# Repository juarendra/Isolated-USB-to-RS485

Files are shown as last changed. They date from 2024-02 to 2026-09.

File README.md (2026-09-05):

# Industrial USB to RS485 Adapter

USB Type-C to isolated half-duplex RS485 interface for Modbus RTU and other UART-based industrial networks.

<p align="center">
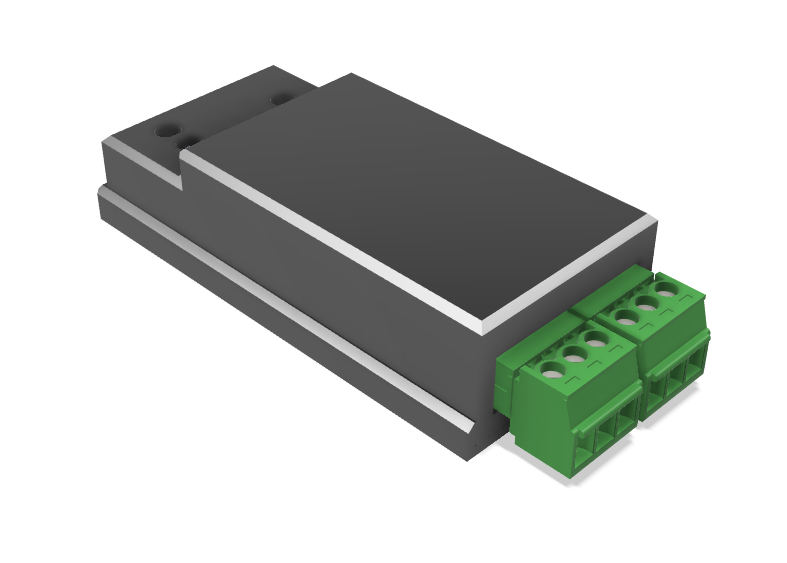
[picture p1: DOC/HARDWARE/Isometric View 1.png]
Industrial USB to RS485 adapter isometric view
  
</p>

## Product Summary

This board converts a USB serial connection into an electrically isolated RS485 bus. It is suitable for connecting a computer, single-board computer, or industrial controller to RS485/Modbus RTU equipment.

```text
USB Type-C -> FT231XS UART -> ADuM1201 isolation -> MAX485 -> RS485 A/B
```

The design files are provided for evaluation, manufacturing, and integration. Read the limitations and validation notes before using the board in a safety-critical or compliance-regulated product.

## Features

- USB Type-C USB 2.0 connection
- FTDI FT231XS USB-to-UART bridge
- 3.3 V UART I/O configuration
- Isolated UART data path using ADuM1201ARZ
- Isolated 5 V supply using IL0505S
- MAX485 half-duplex RS485 transceiver
- RS485 A, B, and isolated ground connector
- Selectable RS485 termination and bias networks
- RS485 transient protection using SM712, TBU, and TISP devices
- TX, RX, and power status indicators
- Resettable USB input protection
- Separate isolated 5 V output connector
- Eagle schematic, board, libraries, Gerber archive, 3D model, and enclosure files

<p align="center">
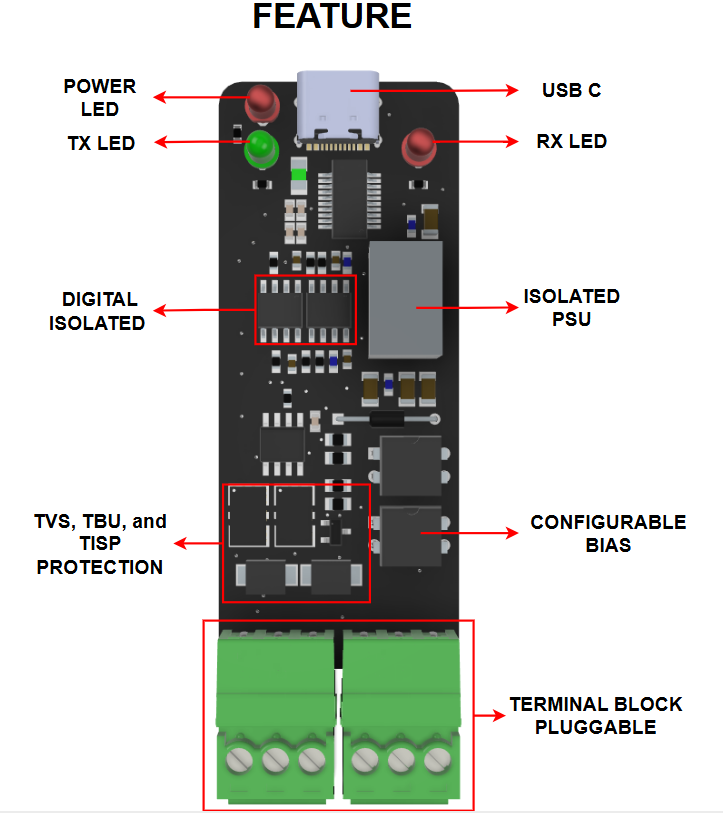
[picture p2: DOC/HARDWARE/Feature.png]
Industrial USB to RS485 adapter feature overview
  
</p>

## Quick Start

1. Connect the board to a host computer using a USB Type-C data cable.
2. Install the FTDI VCP driver if the operating system does not install it automatically.
3. Identify the new serial port.
4. Connect RS485 `A`, `B`, and optionally `GNDA` to the target equipment.
5. Configure the host application for the target baud rate, parity, stop bits, and protocol.
6. Enable termination only when this adapter is at a physical end of the RS485 bus.
7. Enable bias only when this adapter is the designated bias point for the bus.

## Connector Pinout

See the visual pinout: [`DOC/HARDWARE/Pinout.png`](DOC/HARDWARE/Pinout.png).

| Connector | Pin | Function |
|---|---:|---|
| RS485 | 1 | `GNDA` / isolated ground |
| RS485 | 2 | `B` |
| RS485 | 3 | `A` |
| POWER | 1 | `GNDA` |
| POWER | 2 | `VCC`, isolated 5 V |
| POWER | 3 | `VCC`, isolated 5 V |

Confirm connector orientation against the silkscreen and pinout image before wiring.

## Design Files

| Resource | Location |
|---|---|
| Schematic PDF | [`PDF/Schematic.pdf`](PDF/Schematic.pdf) |
| Eagle schematic | [`PCB-EAGLE/IndustrialUSBtoModbus.sch`](PCB-EAGLE/IndustrialUSBtoModbus.sch) |
| Eagle board | [`PCB-EAGLE/IndustrialUSBtoModbus.brd`](PCB-EAGLE/IndustrialUSBtoModbus.brd) |
| Manufacturing Gerbers | [`CAD-CAM/Gerber.zip`](CAD-CAM/Gerber.zip) |
| Production PCB | [`PCB-EAGLE/IndustrialUSBtoModbus_Production.brd`](PCB-EAGLE/IndustrialUSBtoModbus_Production.brd) |
| Production Gerbers | [`CAD-CAM/Gerber_Production.zip`](CAD-CAM/Gerber_Production.zip) |
| Production CAM job | [`CAD-CAM/IndustrialUSBtoModbus v2.cam`](CAD-CAM/IndustrialUSBtoModbus%20v2.cam) |
| Board dimensions | [`DOC/Dimension.pdf`](DOC/Dimension.pdf) |
| STEP model | [`3D/IndustrialUSBtoModbus.step`](3D/IndustrialUSBtoModbus.step) |
| Enclosure models | [`3D/Case/`](3D/Case/) |
| Custom Eagle libraries | [`PCB-EAGLE/lib/`](PCB-EAGLE/lib/) |

Detailed documentation is in [`docs/`](docs/).

For manufacturing, use the files marked **Production**. The production Gerber archive contains Gerber, drill, solder-paste, pick-and-place, job, and ODB++ outputs generated from the production PCB revision.

## Important Limitations

- This is a half-duplex RS485 hardware interface; it does not implement Modbus protocol in hardware.
- RS485 termination, bias values, isolation spacing, and protection ratings require system-level verification.
- Cable length, baud rate, node count, and bus topology depend on the transceiver, cable, and installation.
- Custom FTDI VID/PID programming requires valid ownership/licensing and separate production configuration.

## Buyer Information

Before purchasing or manufacturing, review:

- [`docs/BUYER-GUIDE.md`](docs/BUYER-GUIDE.md) for compatibility and ordering checks
- [`docs/HARDWARE.md`](docs/HARDWARE.md) for circuit behavior and configuration
- [`docs/VALIDATION.md`](docs/VALIDATION.md) for required production tests
- [`docs/FTDI-PROGRAMMING.md`](docs/FTDI-PROGRAMMING.md) for FT231XS production programming
- [`docs/FILES.md`](docs/FILES.md) for the complete repository map

## License

No license is currently declared. Contact the repository owner for permission to manufacture, modify, or redistribute this design.

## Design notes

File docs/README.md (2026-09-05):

# Documentation

Use these pages when evaluating, buying, assembling, or integrating the adapter.

| Guide | Use it for |
|---|---|
| [`BUYER-GUIDE.md`](BUYER-GUIDE.md) | Compatibility, ordering, wiring, and acceptance checks |
| [`HARDWARE.md`](HARDWARE.md) | Signal path, power domains, protection, and switches |
| [`VALIDATION.md`](VALIDATION.md) | Electrical, functional, protection, and environmental tests |
| [`FTDI-PROGRAMMING.md`](FTDI-PROGRAMMING.md) | FT231XS EEPROM and CBUS production profile |
| [`FILES.md`](FILES.md) | Design-file locations and naming rules |

## Recommended Reading Order

1. Read the root [`README.md`](../README.md) for product scope and limitations.
2. Read [`BUYER-GUIDE.md`](BUYER-GUIDE.md) before ordering or wiring.
3. Read [`HARDWARE.md`](HARDWARE.md) before changing the PCB or configuration.
4. Use [`VALIDATION.md`](VALIDATION.md) to define production acceptance tests.

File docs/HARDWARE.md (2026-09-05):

# Hardware Reference

## Signal Path

```text
USB Type-C
  |
  +-- FT231XS-R USB-to-UART
          |
          +-- TXD / RXD / TXEN
                  |
                  +-- ADuM1201ARZ digital isolation
                          |
                          +-- MAX485CSA+ half-duplex transceiver
                                  |
                                  +-- protected A/B connector
```

## Power Domains

| Domain | Nets | Purpose |
|---|---|---|
| USB side | `+5V`, `GND`, `+3V3` | USB connector and FT231XS |
| Isolated bus side | `VCC`, `GNDA` | MAX485, RS485 connector, protection |

`IL0505S` transfers power across the isolation barrier. The two ADuM1201 devices transfer data and direction control without a galvanic signal connection.

## USB-C Configuration

The current revision includes USB-C sink pull-down resistors:

```text
CC1 -> R4 = 5.1 kOhm -> GND
CC2 -> R8 = 5.1 kOhm -> GND
```

These resistors identify the board as a USB device/sink to a USB-C host. `SBU1` and `SBU2` remain unused for this USB 2.0 design.

## RS485 Configuration

`S1` is associated with the single 120 ohm termination resistor `R6`. `S2` is associated with the 4.7 kOhm bias network. Confirm switch position and assembled resistance using a meter because termination must not be enabled at every node.

Recommended topology:

- One termination at each physical end of the main cable.
- Bias enabled at one intentional location, unless the system design specifies otherwise.
- Short stub connections.
- Twisted-pair cable with a suitable characteristic impedance.

### Bias Calculation

The schematic uses `R2 = 4.7 kOhm` from `VCC` to `A` and `R5 = 4.7 kOhm` from `B` to `GNDA`, enabled by `S2`.

For the single 120 ohm termination and an ideal 5 V isolated supply:

```text
I_bias = 5 V / (4.7 kOhm + 120 ohm + 4.7 kOhm)
       = approximately 0.525 mA

V(A) - V(B) = I_bias x 120 ohm
            = approximately 63 mV
```

This is lower than the commonly used 200 mV fail-safe design target. It is not automatically wrong because MAX485 and connected nodes contribute their own behavior, but the complete bus must be calculated and measured. Consider lower bias values only after checking total bus loading, driver current, termination count, and idle common-mode voltage.

With `S2` enabled, record:

- `V(A)` relative to `GNDA`.
- `V(B)` relative to `GNDA`.
- `V(A) - V(B)`.
- Bias current.

Enable bias at one intentional location only. Multiple bias networks can overload the bus and alter common-mode voltage.

### Protection and Fault Specification

The following are design targets and component-level references, not guaranteed board ratings. Fill in the final values after testing the assembled PCB and intended cable installation.

| Parameter | Current design reference | Final value/status |
|---|---|---|
| RS485 common-mode operating range | MAX485 and system specification | TBD by system test |
| Maximum A/B continuous voltage | MAX485 absolute maximum and protection coordination | TBD |
| Maximum line-to-`GNDA` voltage | TBU/TISP/TVS coordination | TBD |
| RS485 short-circuit duration | MAX485 thermal/fault test | TBD |
| TVS standoff voltage | SM712-02HTG datasheet | Verify against bus voltage |
| TBU trigger/current rating | TBU-CA065-200-WH datasheet | Verify per revision |
| TISP voltage/surge rating | TISP4240M3BJR-S datasheet | Verify per test waveform |
| SM712 clamp voltage | SM712-02HTG datasheet and test current | Verify at specified current |
| Surge return path | A/B -> protection -> `GNDA` -> installation return | Validate layout and wiring |

Do not convert these component references into an IEC, EMC, or surge claim without a defined test method and a passing test report.

### Protection Pin Review

Verify the exact manufacturer datasheet and package drawing against the Eagle library before assembly:

| Reference | Part | Required verification |
|---|---|---|
| `D4`, `D5` | `TBU-CA065-200-WH` | Current path pin 1 to pin 3, center pad/pin 2 treatment, package and orientation |
| `D1`, `D6` | `TISP4240M3BJR-S` | Pin polarity, line-to-ground connection, surge path, package |
| `D2` | `SM712-02HTG` | `TVS1`, `TVS2`, `COMMON` mapping, bidirectional behavior, package |

Use a pin-to-pin checklist, not symbol appearance alone:

1. Compare manufacturer pinout with Eagle symbol pin names.
2. Compare symbol pins with package pads in the board file.
3. Trace each line from connector to protection device to `MAX485`.
4. Confirm the TVS common pin returns to `GNDA`.
5. Confirm surge current does not cross the USB isolation barrier.
6. Recheck the physical footprint orientation using a populated-board drawing.

For the current Eagle library, the TBU symbol exposes only pins 1 and 3, while the package contains a center pad/pin 2. Do not infer an electrical function for pin 2 from the symbol. Confirm whether the selected manufacturer package defines it as no-connect, thermal pad, or another connection, then update the library and PCB if required.

## Protection Devices

- `SM712-02HTG`: RS485 line transient suppressor.
- `TBU-CA065-200-WH`: series fault-current limiting devices.
- `TISP4240M3BJR-S`: surge protection devices.
- `0ZCJ0010FF2E`: resettable USB input protection.

Protection performance depends on layout, grounding, surge return path, component tolerances, and installation wiring. Component presence is not equivalent to a compliance rating.

## Indicators

- `LED1`: local power indication.
- `LED3`: FTDI CBUS1 indication, intended for receive activity.
- `LED4`: FTDI CBUS2 indication, intended for transmit activity.

Exact LED behavior depends on FTDI CBUS configuration programmed into the device.

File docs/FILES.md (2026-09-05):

# Repository Map

## Main Folders

| Folder | Contents |
|---|---|
| `CAD-CAM/` | Manufacturing output archives |
| `DOC/` | Buyer-facing images and mechanical documents |
| `PDF/` | Printable schematic documentation |
| `PCB-EAGLE/` | Eagle source files and custom libraries |
| `3D/` | Board, enclosure, and mechanical models |
| `docs/` | Product, hardware, buyer, and validation documentation |

## Production Outputs

Use these files for the current manufacturing package:

| Output | Location |
|---|---|
| Production Eagle board | [`PCB-EAGLE/IndustrialUSBtoModbus_Production.brd`](../PCB-EAGLE/IndustrialUSBtoModbus_Production.brd) |
| Production Gerber/ODB++ archive | [`CAD-CAM/Gerber_Production.zip`](../CAD-CAM/Gerber_Production.zip) |
| Production CAM job | [`CAD-CAM/IndustrialUSBtoModbus v2.cam`](../CAD-CAM/IndustrialUSBtoModbus%20v2.cam) |

The production archive includes copper, solder mask, solder paste, silkscreen, board profile, drill, job, ODB++ data, and front-side pick-and-place output. Confirm the PCB revision and fabrication house rules before ordering.

## Naming Convention

New files should use:

- Uppercase folder names only for legacy design folders.
- Lowercase `docs/` for GitHub documentation.
- Lowercase, hyphen-separated names for new documentation files.
- Descriptive asset names, for example `rs485-adapter-pinout.png`.
- Stable revision suffixes when output changes, for example `gerbers-r02.zip`.

Existing Eagle source names are retained to avoid breaking library links and manufacturing references.

## Legacy Files

Files with names such as `IndustrialUSBtoModbus.b#1` are Eagle backup artifacts. They are retained for traceability but should not be used as the primary source. Use the `.sch` and `.brd` files listed above.

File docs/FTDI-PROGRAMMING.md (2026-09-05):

# FTDI Production Programming

The schematic assigns FTDI CBUS pins to RS485 direction control and activity indicators. These functions are configured in FTDI EEPROM; they are not guaranteed by PCB wiring alone.

## Required Profile

Program and record one approved profile for every production batch.

| EEPROM field | Required value |
|---|---|
| VID | Use an owned/licensed VID; do not copy another vendor's VID |
| PID | Approved product PID paired with the VID |
| Manufacturer string | Product owner approved text |
| Product description | `Industrial USB to RS485` or approved text |
| Serial number | Unique per device, or explicitly disabled by policy |
| VCP driver | Enabled if the product is used as a virtual COM port |
| CBUS0 | `TXDEN` / RS485 transmit-enable function, if supported by the exact FT231XS configuration tool |
| CBUS1 | `RXLED#` activity indication |
| CBUS2 | `TXLED#` activity indication |
| Inversion | Disabled unless validated by logic measurement |

## Important Direction-Control Clarification

The schematic net `TXEN_` connects FTDI `CBUS0` through `R33` to one ADuM1201 channel. The isolated output of that channel drives MAX485 `DE` and `/RE` together.

The exact CBUS0 function must produce the required timing and polarity for half-duplex RS485. Use the FTDI transmit-data-enable function, commonly shown as `TXDEN`, when available. Do not use `TXLED#` for direction control. Validate with an oscilloscope:

- `TXD` activity.
- `TXEN_` on the USB side.
- Isolated direction signal.
- MAX485 `DE`.
- MAX485 `/RE`.
- RS485 A/B driver activity.

If CBUS0 is used as a direction-control output, select the correct FTDI mode supported by the exact FT231XS revision and validate driver turn-around timing. Keep LED functions on CBUS1/CBUS2 only if the programmed modes match the schematic intent.

### Important FTDI Clarification

`TXDEN` is a hardware transmit-enable indication generated from USB-UART transmit activity. It is not the same signal as `TXD`, and it must remain asserted long enough for the complete outgoing UART character stream. Check the exact FTDI FT231X datasheet and FT_PROG option list for the installed device revision before freezing the EEPROM profile.

The schematic currently routes `CBUS0` through `R33` and an ADuM1201 channel to both MAX485 `DE` and `/RE`. That is an intentional half-duplex arrangement: transmit mode enables the driver and disables the receiver. Confirm that the inactive state is safe during USB attach, reset, suspend, and disconnect. A temporary incorrect state can cause bus contention.

### Recommended Production Record

Store the following with each hardware revision:

- FTDI part marking and silicon revision.
- FT_PROG version.
- EEPROM profile file or captured settings.
- VID/PID ownership record.
- Product and manufacturer strings.
- Serial-number allocation range.
- CBUS0/1/2 settings and polarity.
- Oscilloscope capture showing UART, `TXEN_`, `DE`, `/RE`, and A/B.

## Production Procedure

1. Connect the board to a controlled USB host or FTDI programming fixture.
2. Read and save the original EEPROM configuration.
3. Program the approved VID, PID, strings, serial policy, VCP setting, CBUS functions, and inversion settings.
4. Power-cycle the board.
5. Confirm USB enumeration and descriptor values.
6. Confirm COM-port creation.
7. Verify TX/RX indicators.
8. Verify RS485 direction timing and loopback communication.
9. Save the programmed profile and device serial number in the production record.

Never use an unlicensed VID/PID or ship devices with an untracked serial-number policy.

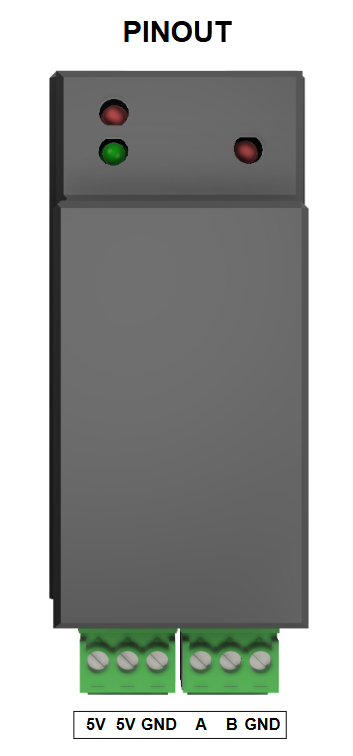
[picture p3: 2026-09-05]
DOC/HARDWARE/Pinout.png

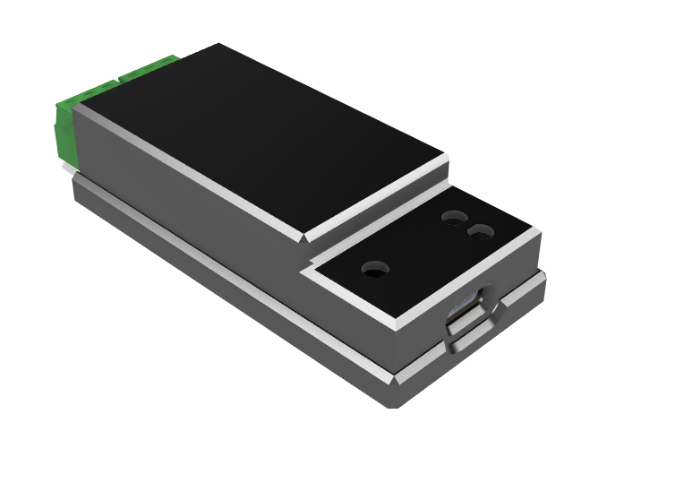
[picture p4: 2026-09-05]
DOC/HARDWARE/Isometric View 2.png

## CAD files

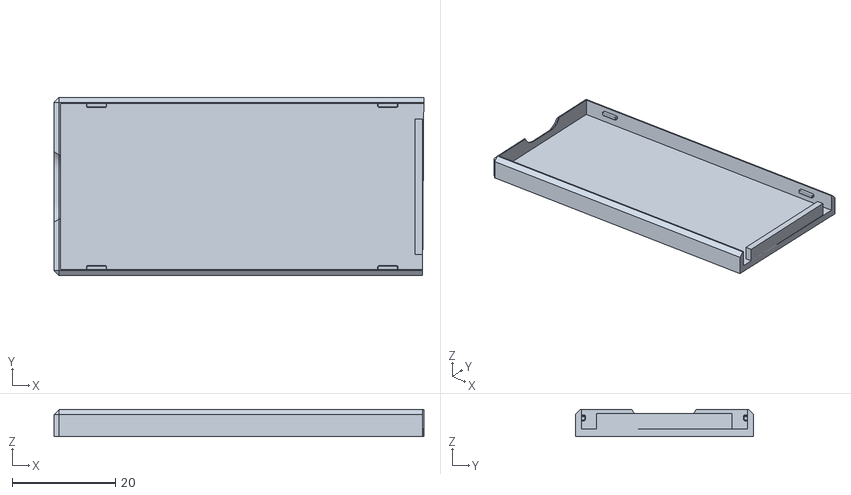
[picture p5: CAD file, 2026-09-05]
3D/Case/Bottom.stl
71.7 x 34.6 x 5.25

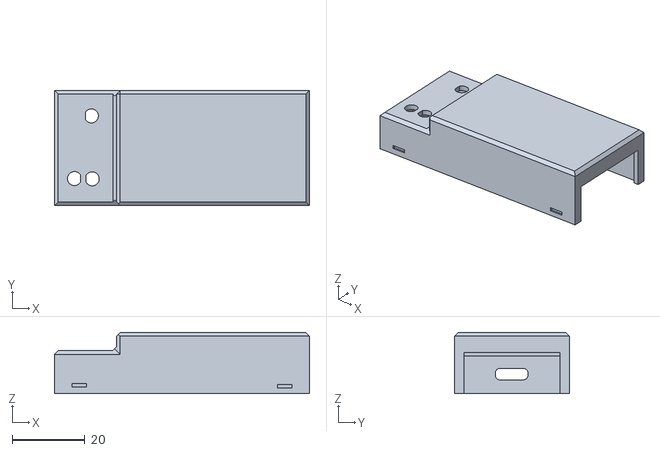
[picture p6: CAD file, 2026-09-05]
3D/Case/TOP.stl
70.0 x 31.6 x 16.8

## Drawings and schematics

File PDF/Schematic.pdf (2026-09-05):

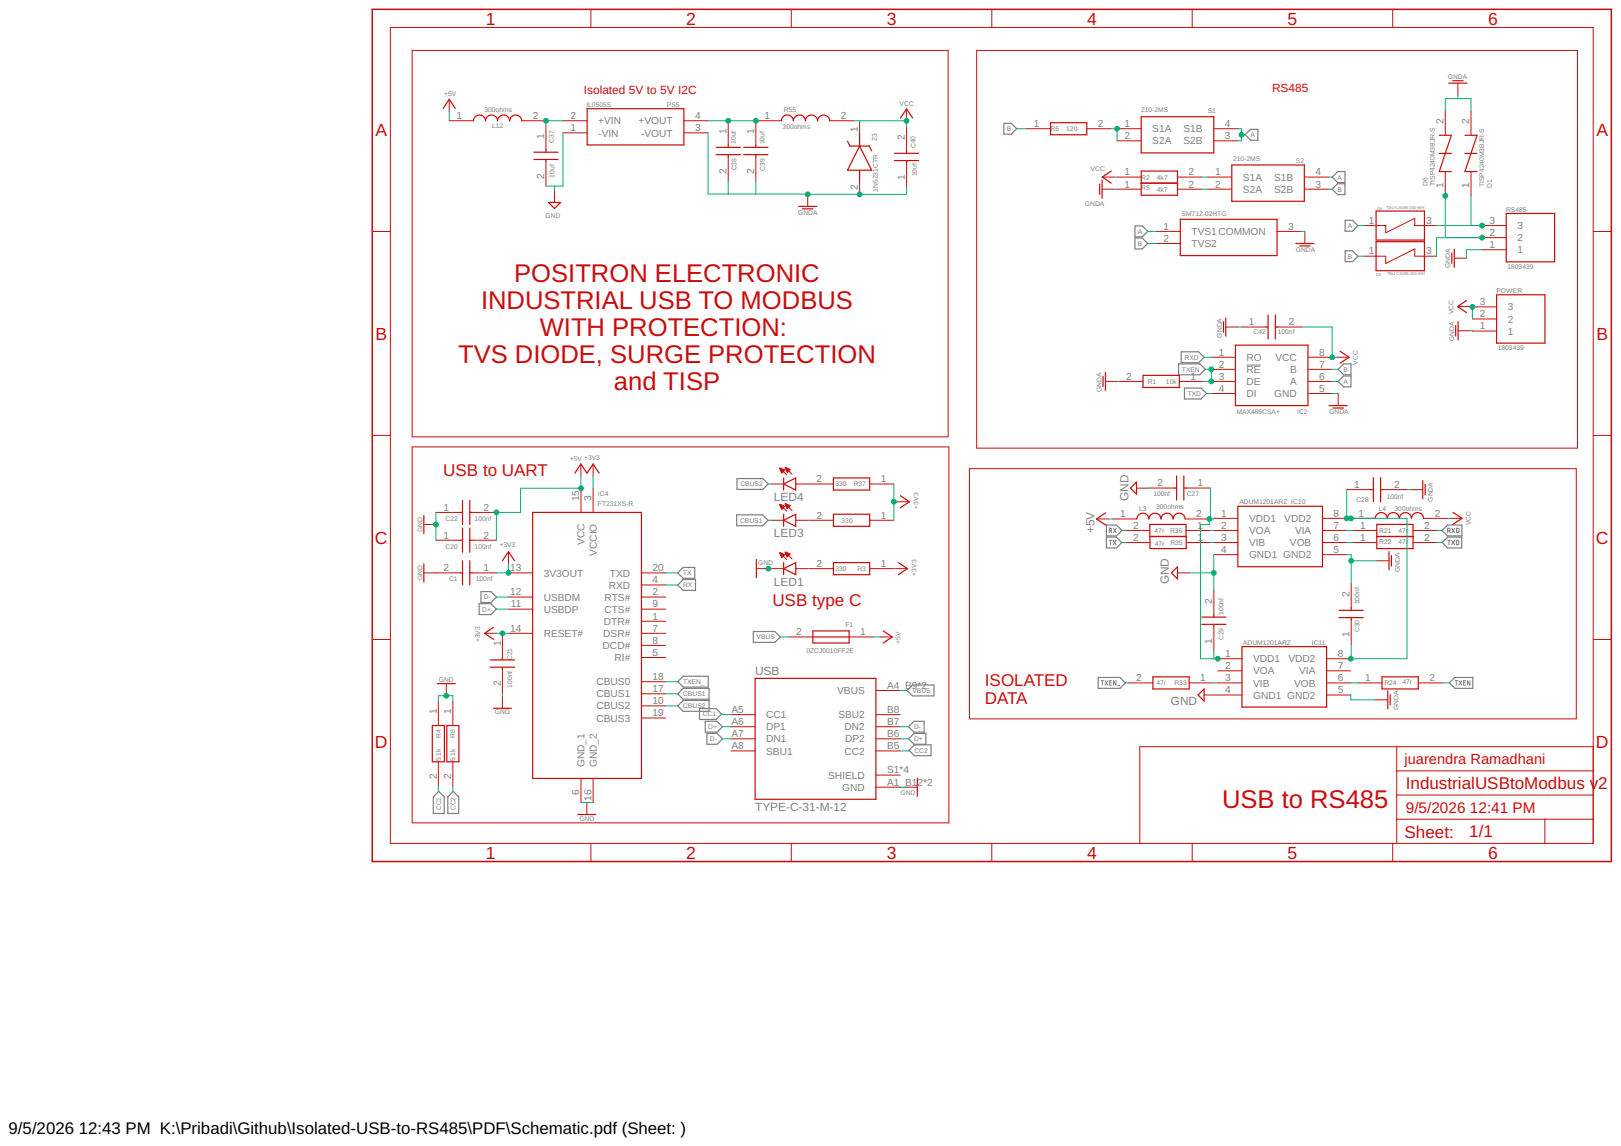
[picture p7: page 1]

GND
POSITRON ELECTRONIC
INDUSTRIAL USB TO MODBUS
WITH PROTECTION:
TVS DIODE, SURGE PROTECTION

9/5/2026 12:43 PM K:\Pribadi\Github\Isolated-USB-to-RS485\PDF\Schematic.pdf (Sheet: )

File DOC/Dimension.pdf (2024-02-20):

# 26.59 ACTUAL

12.17 3

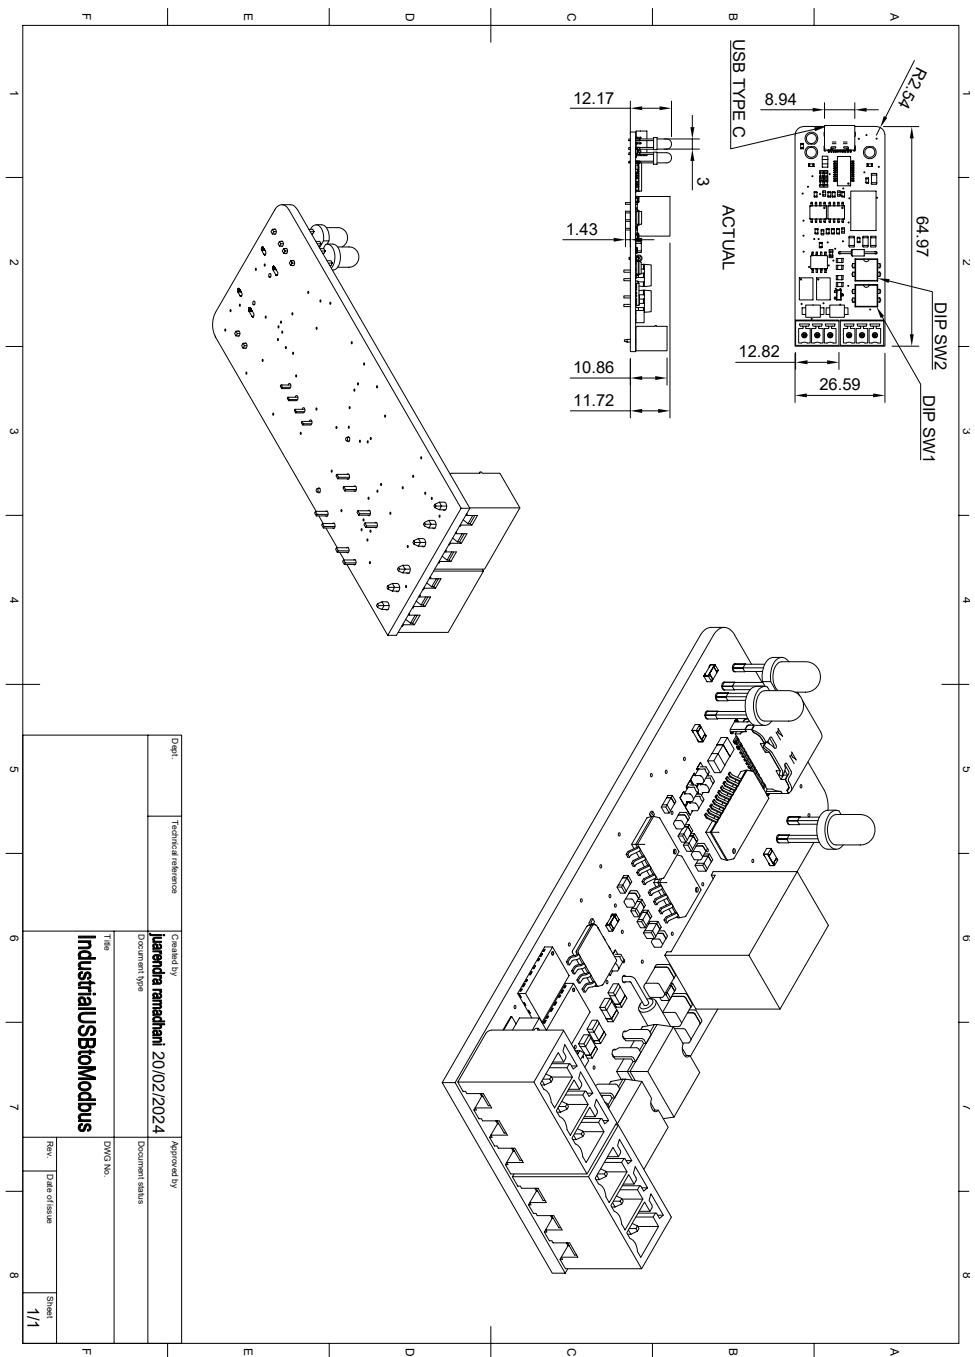
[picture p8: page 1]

1 A 2 3 4 5 6 7 8 1 2 3 4 5 6 7 8 FEDCB FEDCBA Dept. Technical reference Created by Approved by Title DWG No. Document type Document status Rev. Date of issue Sheet 20/02/2024 1/1 64.97

12.82 DIP SW1 DIP SW2 USB TYPE C

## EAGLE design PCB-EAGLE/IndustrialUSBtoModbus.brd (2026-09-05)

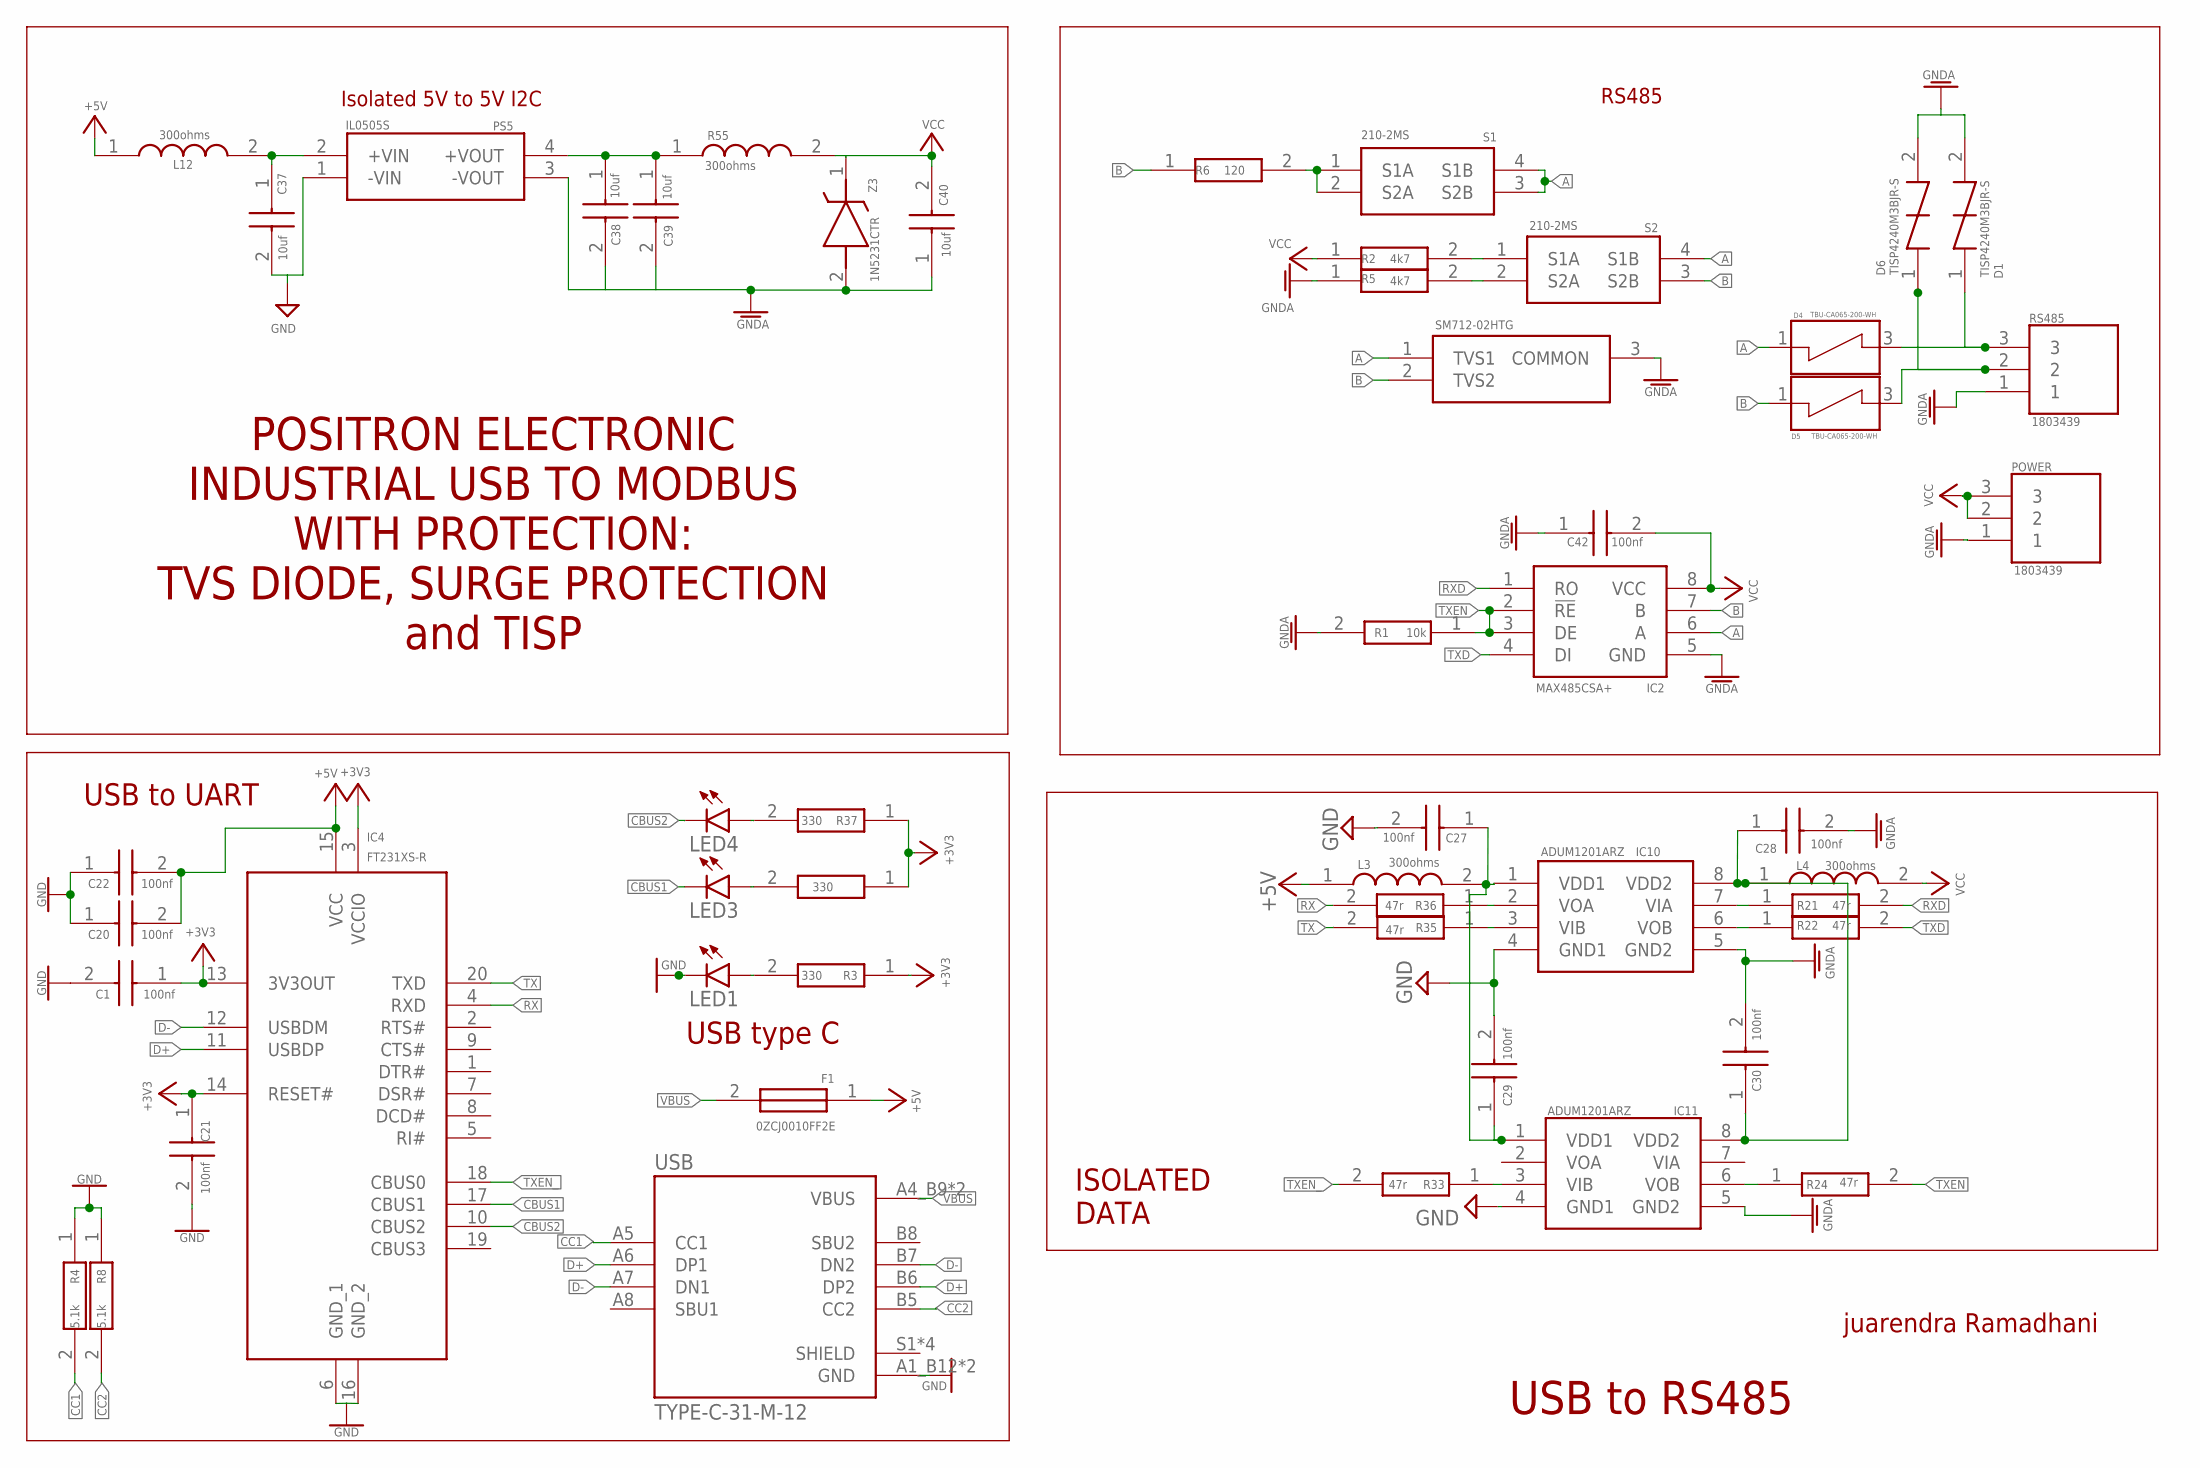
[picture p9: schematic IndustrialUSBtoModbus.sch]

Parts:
C1, C20, C21, C22, C27, C28, C29, C30, C42: 100nf; CAPC1608X87N
C37, C38, C39, C40: 10uf; CAPC3216X170N
D1, D6: TISP4240M3BJR-S; TISP4240M3BJRS
D2: SM712-02HTG; SOT95P237X111-3N
D4, D5: TBU-CA065-200-WH; DIOC650X400X100N
F1: 0ZCJ0010FF2E; FUSC3216X75N
IC2: MAX485CSA+; SOIC127P600X175-8N
IC4: FT231XS-R; SOP64P599X175-20N
IC10, IC11: ADUM1201ARZ; SOIC127P600X175-8N
L3, L4, L12: 300ohms; INDC1608X95N
LED1, LED3, LED4: LED3MM
POWER: 1803439
PS5: IL0505S
R1: 10k; ERJ3EK_(0603)
R2, R5: 4k7; RESC2012X65N
R3, R37, R38: 330; ERJH3
R4, R8: 5.1k; ERJH3
R6: 120; RESC2012X65N
R21, R22, R24, R33, R35, R36: 47r; RESC1608X55N
R55: 300ohms; INDC1608X95N
RS485: 1803439
S1, S2: 210-2MS; DIP775W63P254L655H458Q4N
USB: TYPE-C-31-M-12; HRO_TYPE-C-31-M-12
Z3: 1N5231CTR; DIOAD1068W53L380D172

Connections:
+3V3: C1.1, C21.1, IC4.3 (VCCIO), IC4.13 (3V3OUT), IC4.14 (RESET#), R3.1, R37.1, R38.1
+5V: C20.2, C22.2, F1.1, IC4.15 (VCC), L3.1, L12.1
A: D2.1 (TVS1), D4.1, IC2.6 (A), S1.3 (S2B), S1.4 (S1B), S2.4 (S1B)
B: D2.2 (TVS2), D5.1, IC2.7 (B), R6.1, S2.3 (S2B)
CBUS1: IC4.17 (CBUS1), LED3.K (C)
CBUS2: IC4.10 (CBUS2), LED4.K (C)
CC1: R4.2, USB.A5 (CC1)
CC2: R8.2, USB.B5 (CC2)
D+: IC4.11 (USBDP), USB.A6 (DP1), USB.B6 (DP2)
D-: IC4.12 (USBDM), USB.A7 (DN1), USB.B7 (DN2)
GND: C1.2, C20.1, C21.2, C22.1, C27.2, C29.2, C37.2, IC4.6 (GND_1), IC4.16 (GND_2), IC10.4 (GND1), IC11.4 (GND1), LED1.K (C), PS5.1 (-VIN), R4.1, R8.1, USB.A1_B12 (GND), USB.B1_A12 (GND)
GNDA: C28.2, C30.2, C38.2, C39.2, C40.1, C42.1, D1.2, D2.3 (COMMON), D6.2, IC2.5 (GND), IC10.5 (GND2), IC11.5 (GND2), POWER.1, PS5.3 (-VOUT), R1.2, R5.1, RS485.1, Z3.2 (A)
unnamed: C28.1, C30.1, IC10.8 (VDD2), IC11.8 (VDD2), L4.1
unnamed: IC10.6 (VOB), R22.1
unnamed: LED3.A, R38.2
unnamed: IC10.7 (VIA), R21.1
unnamed: R2.2, S2.1 (S1A)
unnamed: R5.2, S2.2 (S2A)
unnamed: D5.3, D6.1, RS485.2
unnamed: LED1.A, R3.2
unnamed: D1.1, D4.3, RS485.3
unnamed: R6.2, S1.1 (S1A), S1.2 (S2A)
unnamed: LED4.A, R37.2
unnamed: C27.1, C29.1, IC10.1 (VDD1), IC11.1 (VDD1), L3.2
unnamed: IC10.3 (VIB), R35.1
unnamed: IC10.2 (VOA), R36.1
unnamed: IC11.6 (VOB), R24.1
unnamed: IC11.3 (VIB), R33.1
unnamed: C37.1, L12.2, PS5.2 (+VIN)
unnamed: C38.1, C39.1, PS5.4 (+VOUT), R55.1
RX: IC4.4 (RXD), R36.2
RXD: IC2.1 (RO), R21.2
TX: IC4.20 (TXD), R35.2
TXD: IC2.4 (DI), R22.2
TXEN: IC2.2 (!RE), IC2.3 (DE), R1.1, R24.2
TXEN_: IC4.18 (CBUS0), R33.2
VBUS: F1.2, USB.A4_B9 (VBUS), USB.B4_A9 (VBUS)
VCC: C40.2, C42.2, IC2.8 (VCC), L4.2, POWER.2, POWER.3, R2.1, R55.2, Z3.1 (K)

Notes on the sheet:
USB to UART
USB type C
USB to RS485
juarendra Ramadhani
RS485
Isolated 5V to 5V I2C
ISOLATED DATA
POSITRON ELECTRONIC INDUSTRIAL USB TO MODBUS WITH PROTECTION: TVS DIODE, SURGE PROTECTION and TISP

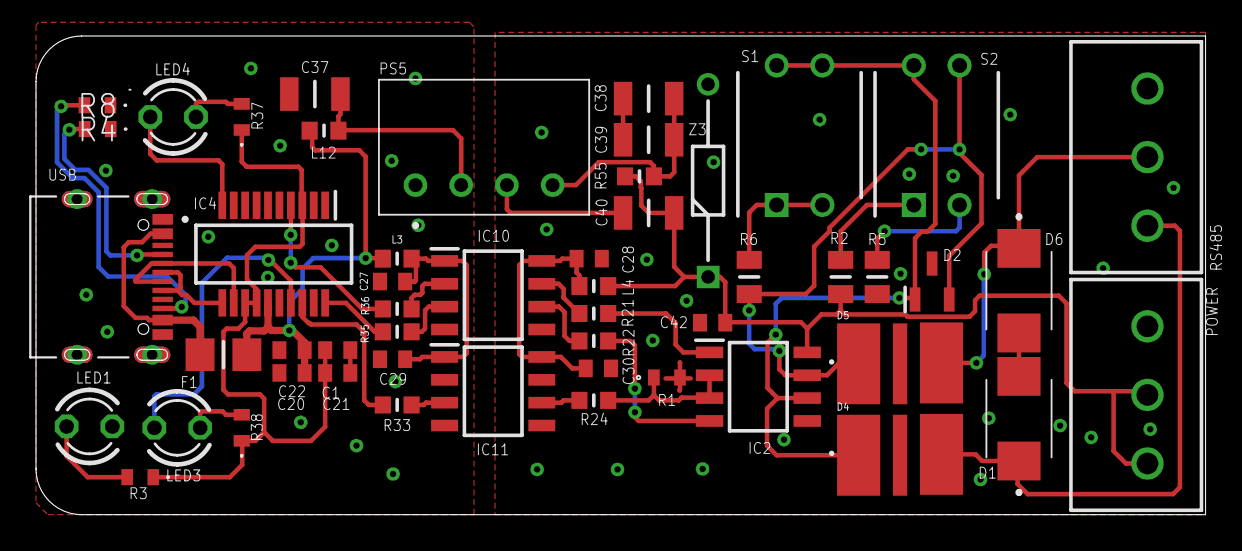
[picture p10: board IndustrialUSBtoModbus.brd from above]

Board: 2 copper layers, 65.0 x 26.6 mm, 52 parts (0 on the bottom side), 38 nets.

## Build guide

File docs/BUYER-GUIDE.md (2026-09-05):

# Buyer Guide

## What This Product Does

Industrial USB to RS485 Adapter provides a USB serial port for an isolated RS485 network. Typical applications include:

- Modbus RTU commissioning and service
- PC-to-PLC communication
- Industrial sensor and meter networks
- Building automation and instrumentation
- Embedded Linux or single-board computer gateways

## What To Confirm Before Ordering

- Host has USB 2.0 support and a suitable USB Type-C data cable.
- Target equipment uses 2-wire half-duplex RS485.
- Target wiring identifies `A` and `B` polarity clearly; vendor naming is not always consistent.
- Bus has only two physical termination points.
- Adapter position in bus is known before selecting termination and bias switches.
- Required baud rate and cable length are within the tested system limits.
- Isolated 5 V output current requirement is compatible with IL0505S capability.
- Enclosure, connector, and mounting requirements match the included mechanical files.

## Included Design Package

- Production Gerber archive
- Eagle schematic and PCB source
- Custom component libraries
- Schematic PDF
- Board dimension PDF
- STEP board model
- STL enclosure models
- Connector pinout and hardware images

## Not Included

- USB cable
- FTDI driver support from this repository
- Modbus software or protocol stack
- RS485 cable or termination accessories
- Regulatory certification
- Guaranteed assembled hardware unless supplied separately by the seller

## Safe Wiring Sequence

1. Power down the connected RS485 system.
2. Verify connector pin numbers against the silkscreen and pinout image.
3. Connect `A` to `A` and `B` to `B`; reverse only after checking equipment documentation.
4. Connect `GNDA` only where the installation requires a reference conductor.
5. Check for shorts and unwanted connection between USB ground and `GNDA`.
6. Connect USB and configure the serial port.
7. Test with low-rate traffic before increasing bus speed.

## Purchase Acceptance Checklist

- USB device enumerates.
- TX, RX, and power indicators operate as expected.
- RS485 transmit and receive operate in both directions.
- USB ground and `GNDA` remain electrically isolated.
- Termination switch produces the specified resistance.
- Bias switch produces the specified idle-bus bias.
- Protection and isolation tests pass the agreed acceptance criteria.

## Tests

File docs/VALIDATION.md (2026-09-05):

# Validation Plan

Complete these checks on the exact assembled revision before selling or publishing compliance claims.

## Electrical Checks

- Measure USB-side to isolated-side resistance and insulation resistance.
- Confirm isolated output voltage at minimum and maximum expected USB input.
- Confirm output ripple and converter temperature under load.
- Measure RS485 A-B termination in every switch position.
- Measure bias voltage and current in every switch position.
- Confirm MAX485 `DE` and `/RE` direction timing.
- Confirm no unintended copper, mounting hardware, or shield path bridges the isolation barrier.

## RS485 Protection Characterization

Record measured values against the exact component datasheets and test fixture:

| Measurement | Test condition | Result |
|---|---|---|
| `A` to `GNDA` withstand/clamp | Defined surge or fault waveform | TBD |
| `B` to `GNDA` withstand/clamp | Defined surge or fault waveform | TBD |
| `A` to `B` withstand/clamp | Defined differential waveform | TBD |
| TBU trip current/time | Defined source impedance and pulse | TBD |
| TBU recovery behavior | After pulse and after fault removal | TBD |
| TISP trigger/clamp behavior | Defined pulse and return path | TBD |
| SM712 clamp voltage | Defined current and pulse duration | TBD |
| MAX485 short-circuit duration | A/B shorted under controlled supply | TBD |

Do not enter a voltage or time as a product rating merely because it appears in a component datasheet. The board rating is limited by the complete current path: connector, copper, TBU, TISP, TVS, ground return, MAX485, spacing, and enclosure.

## Functional Checks

- USB enumeration on supported operating systems.
- UART loopback test.
- RS485 transmit and receive test.
- Modbus RTU request/response test.
- Repeated direction changes at the target baud rate.
- Operation with and without termination enabled.
- Operation with representative cable length and node count.

## Protection and Environmental Checks

- Contact and air discharge ESD testing at accessible points.
- EFT testing on USB and RS485 cables.
- Surge testing using the intended installation and return path.
- RS485 short-to-ground and line-to-line fault testing.
- Hot and cold operating tests.
- Long-duration traffic and thermal soak test.

Record test equipment, revision, wiring, pass/fail criteria, and results. Do not use this document as a certification statement.

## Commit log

2026-09-05 docs: add buyer-ready project documentation
    [Bottom.stl, IndustrialUSBtoModbus.brd, TOP.stl]
2026-09-05 feat: update USB RS485 hardware revision
    [IndustrialUSBtoModbus.brd, IndustrialUSBtoModbus.sch]
2026-09-05 feat: add production manufacturing outputs
    [IndustrialUSBtoModbus_Production.brd]
